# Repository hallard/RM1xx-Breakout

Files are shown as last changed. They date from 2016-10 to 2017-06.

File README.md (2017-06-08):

Laird LoRa/Bluetooth Low Energy Module breakout for RM1xx modules
=================================================================

These breakout are used to hold Lairdtech Lora/BLE [module][1] RM186 (868MHz) or RM191 (915MHz). There are 2 versions, one minimal to place on veroboard kind and one other the be placed on breadboard
They contains the following features

- Full version
  - I2C Pullups placement
  - CR2540 or LIR2450 battery holder
  - Resistor divider to measure battery voltage using analog pin
  - On board 3V3 regulator (so Lipo can be used) 
  - JST2 Lipo connector
  - FTDI connector
  - Prog/Debug connector footprint
  - Breadboard friendly

- Minimal version
  - I2C Pullups placement
  - Veroboard friendly

Version 1.1 fix the MCP1303 Regulator that was reversed

Boards have been ordered at PCBs.io and have been tested and they are working fine.

Detailed Description
====================

Look at the schematics for more informations.

- Full version 
  - Place R6 and R7 divider only if you need to measure Vbat from Analog SIO04
  - Place R3 and R4 only if you whan to use I2C devices

- Minimal version 
  - Place R1 and R2 only if you whan to use I2C devices

### Schematic 

**Full version**
Click to enlarge 
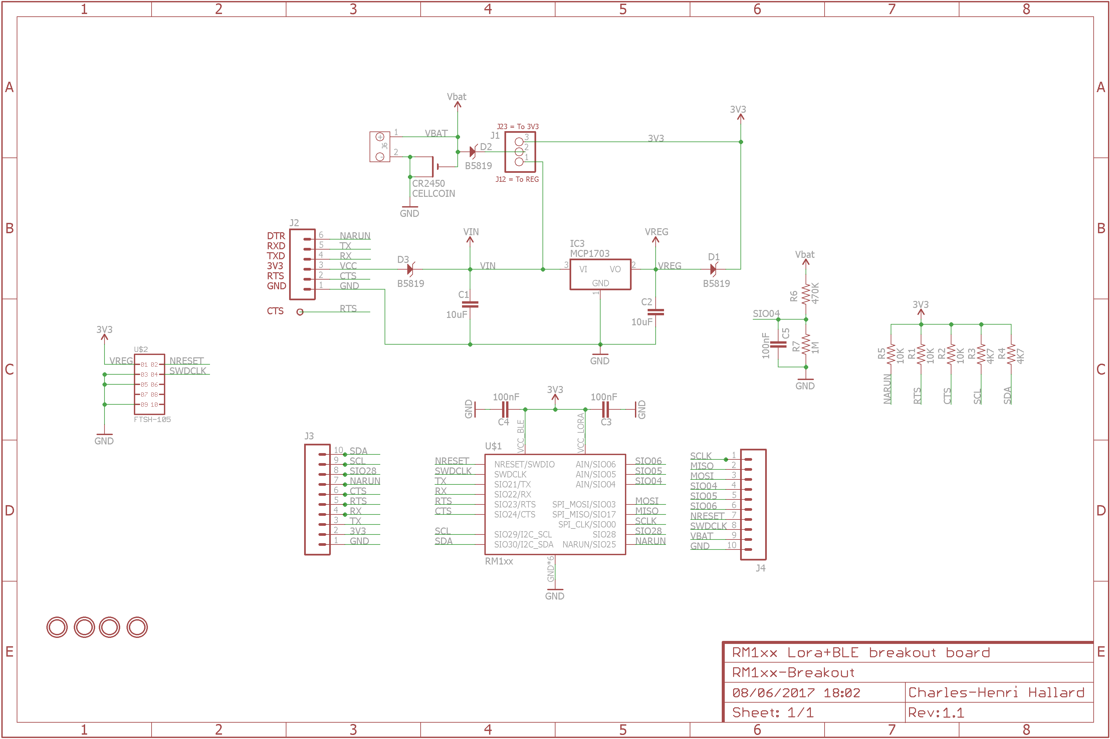
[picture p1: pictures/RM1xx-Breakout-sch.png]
  

**Minimal version**
Click to enlarge 
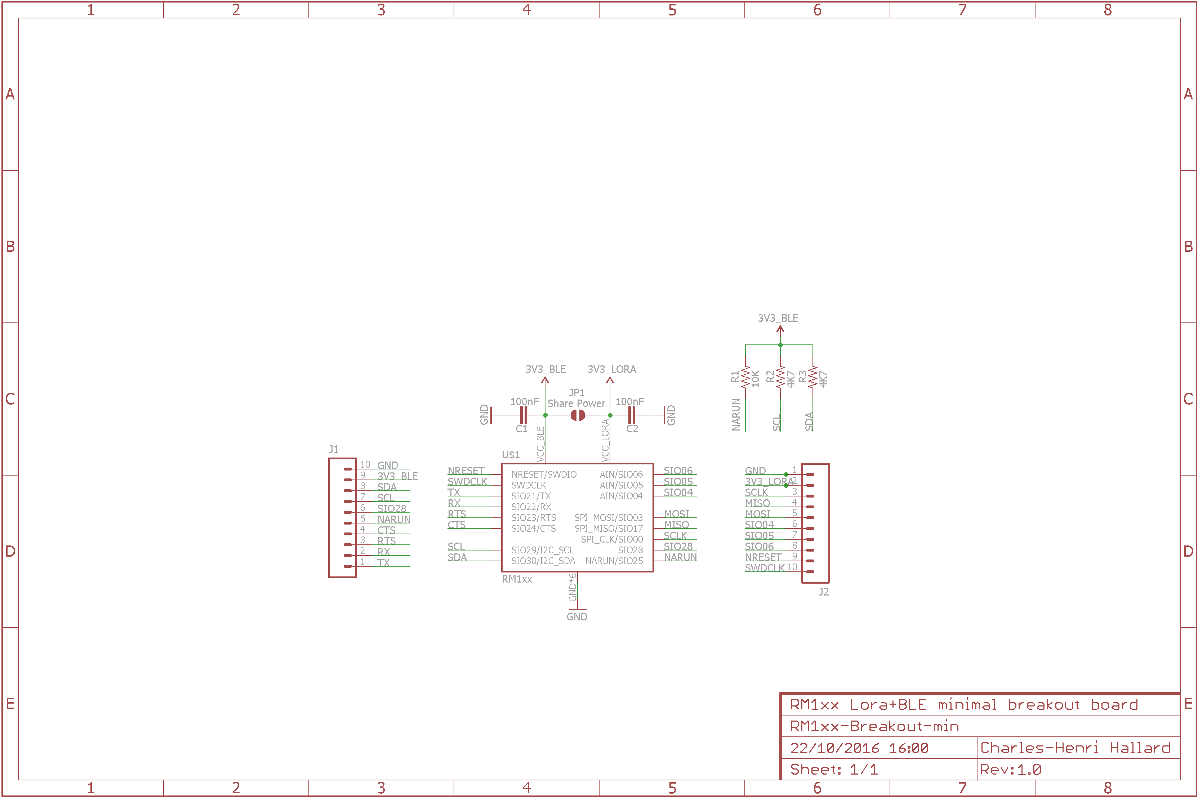
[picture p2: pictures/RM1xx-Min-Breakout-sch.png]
  

### Boards (Full Version)

**Top**    

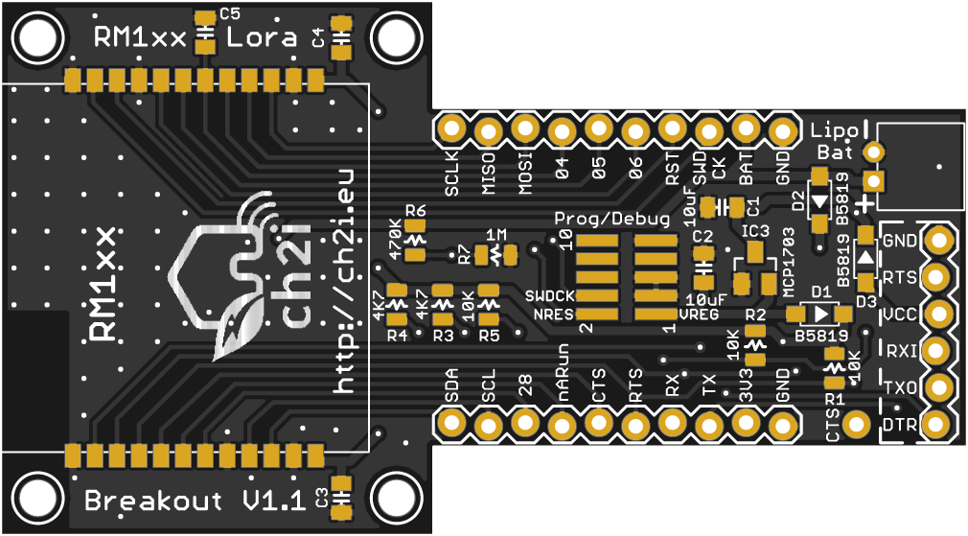
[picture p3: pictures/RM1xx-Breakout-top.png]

    
**Bottom**    

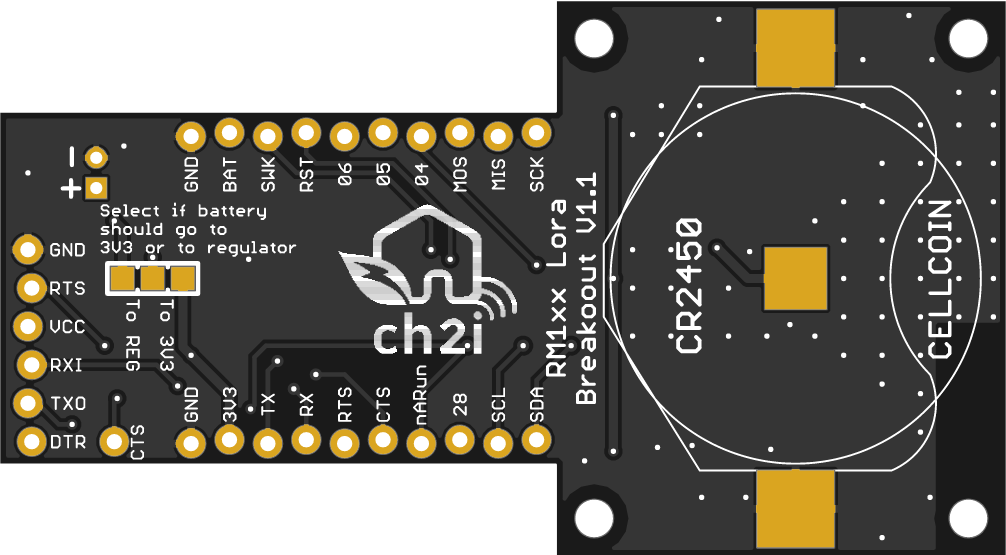
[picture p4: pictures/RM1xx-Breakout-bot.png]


You can order the PCB of this board at [PCBs.io][3] if you do so, PCBs.io give me little discount that allow me to buy some new created boards.

### Boards (Minimal Version)

**Top**    

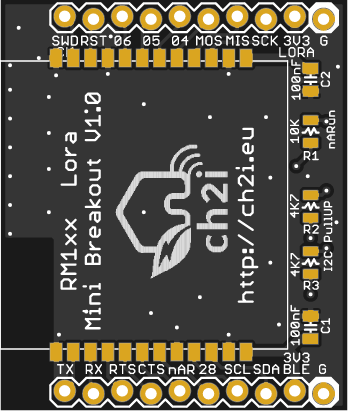
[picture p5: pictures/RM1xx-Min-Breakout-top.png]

    
**Bottom**    

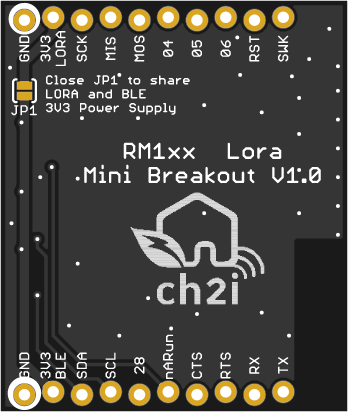
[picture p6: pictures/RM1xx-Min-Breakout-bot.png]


You can order the PCB of this minimal breakout board at [PCBs.io][4] if you do so, PCBs.io give me little discount that allow me to buy some new created boards.

### Assembled boards

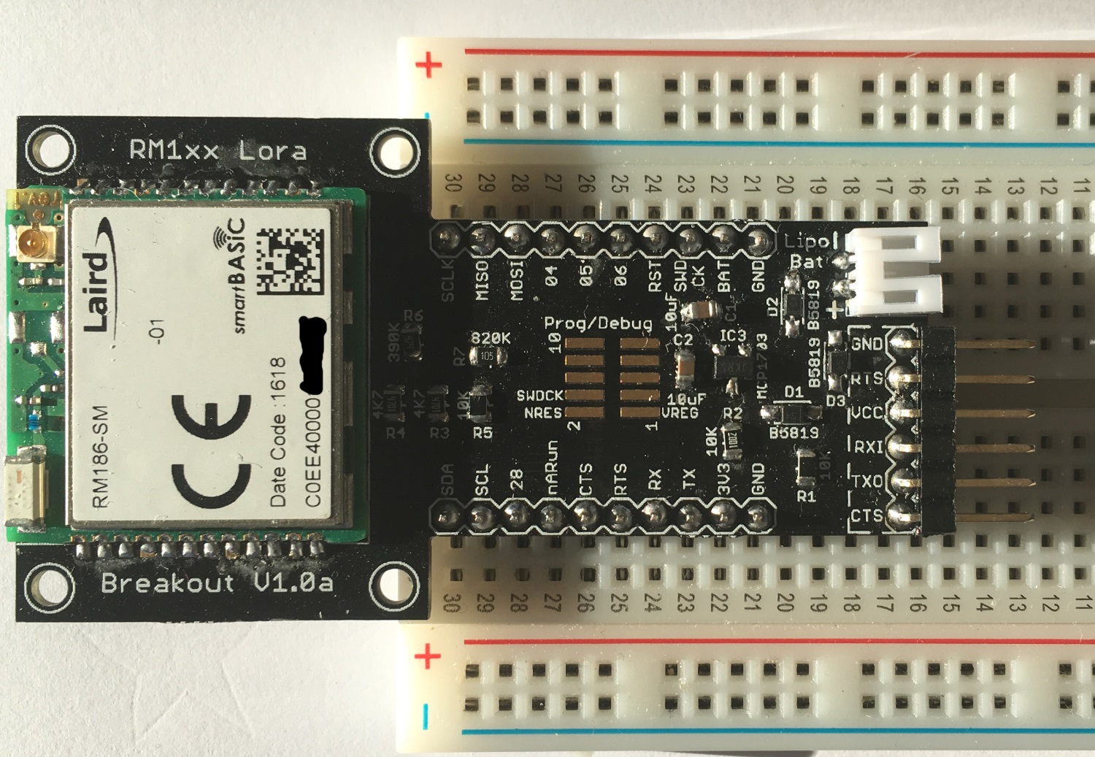
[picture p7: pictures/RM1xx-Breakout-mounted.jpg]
assembled


###License

You can do whatever you like with this design.

###Misc
See news and other projects on my [blog][2] 

[1]: http://www.lairdtech.com/products/rm1xx-lora-modules
[2]: https://hallard.me
[3]: https://PCBs.io/share/rY657 
[4]: https://PCBs.io/share/49GYW

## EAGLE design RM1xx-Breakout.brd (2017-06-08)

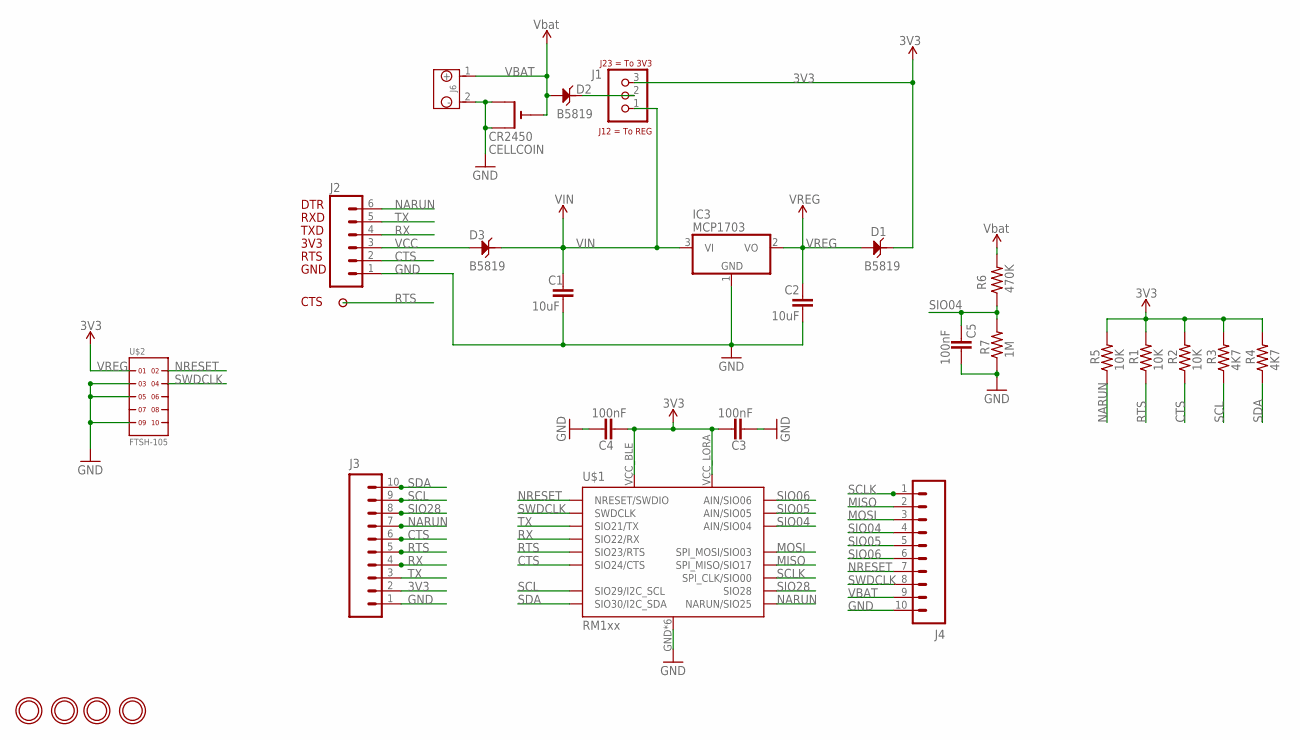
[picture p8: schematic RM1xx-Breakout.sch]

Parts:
C1, C2: 10uF; 0805-CAP
C3, C4, C5: 100nF; 0805-CAP
CELLCOIN: CR2450; CR2450-SMD
D1, D2, D3: B5819; SOD123-2.7X1.6
IC3: MCP1703; SOT23
J1: JUMPER_1X30805; JP3_0805
J2: M06SIP_LOCK; 1X06-SIP_LOCK
J3, J4: M10LOCK; 1X10_LOCK
J6: Lipo Battery; 2P-2.0-90D
P1: PADNORMAL; PAD
R1, R2, R5: 10K; 0805-RES
R3, R4: 4K7; 0805-RES
R6: 470K; 0805-RES
R7: 1M; 0805-RES
U$1: RM1xx; RM1XX
U$2: FTSH-105; FTSH-105-01-XXX-DV-K
U$3, U$6, U$7, U$8: MOUNTINGHOLE2.5; MOUNTINGHOLE_2.5_PLATED

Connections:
3V3: C3.1, C4.2, D1.2, J1.3, J3.2, R1.2, R2.2, R3.2, R4.2, R5.2, U$1.VCC_BLE, U$1.VCC_LORA
CTS: J2.2, J3.6, R2.1, U$1.SIO24 (SIO24/CTS)
GND: C1.2, C2.2, C3.2, C4.1, C5.1, CELLCOIN.+$1 (+), CELLCOIN.+$2 (+1), IC3.1 (GND), J2.1, J3.1, J4.10, J6.2 (-), R7.1, U$1.GND, U$1.GND1 (GND), U$1.GND2 (GND), U$1.GND3 (GND), U$1.GND4 (GND), U$1.GND5 (GND), U$2.3, U$2.5, U$2.9
MISO: J4.2, U$1.SIO17 (SPI_MISO/SIO17)
MOSI: J4.3, U$1.SIO03 (SPI_MOSI/SIO03)
unnamed: D2.2, J1.2
NARUN: J2.6, J3.7, R5.1, U$1.SIO25 (NARUN/SIO25)
NRESET: J4.7, U$1.RESET (NRESET/SWDIO), U$2.2
RTS: J3.5, P1.1, R1.1, U$1.SIO23 (SIO23/RTS)
RX: J2.4, J3.4, U$1.SIO22 (SIO22/RX)
SCL: J3.9, R3.1, U$1.SIO29 (SIO29/I2C_SCL)
SCLK: J4.1, U$1.SIO00 (SPI_CLK/SIO00)
SDA: J3.10, R4.1, U$1.SIO30 (SIO30/I2C_SDA)
SIO04: C5.2, J4.4, R6.1, R7.2, U$1.SIO04 (AIN/SIO04)
SIO05: J4.5, U$1.SIO05 (AIN/SIO05)
SIO06: J4.6, U$1.SIO06 (AIN/SIO06)
SIO28: J3.8, U$1.SIO28
SWDCLK: J4.8, U$1.SWDCLK, U$2.4
TX: J2.5, J3.3, U$1.SIO21 (SIO21/TX)
VBAT: CELLCOIN.-, D2.1, J4.9, J6.1 (+), R6.2
VCC: D3.1, J2.3
VIN: C1.1, D3.2, IC3.3 (VI), J1.1
VREG: C2.1, D1.1, IC3.2 (VO), U$2.1

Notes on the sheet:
DTR
RXD
TXD
3V3
RTS
GND
CTS

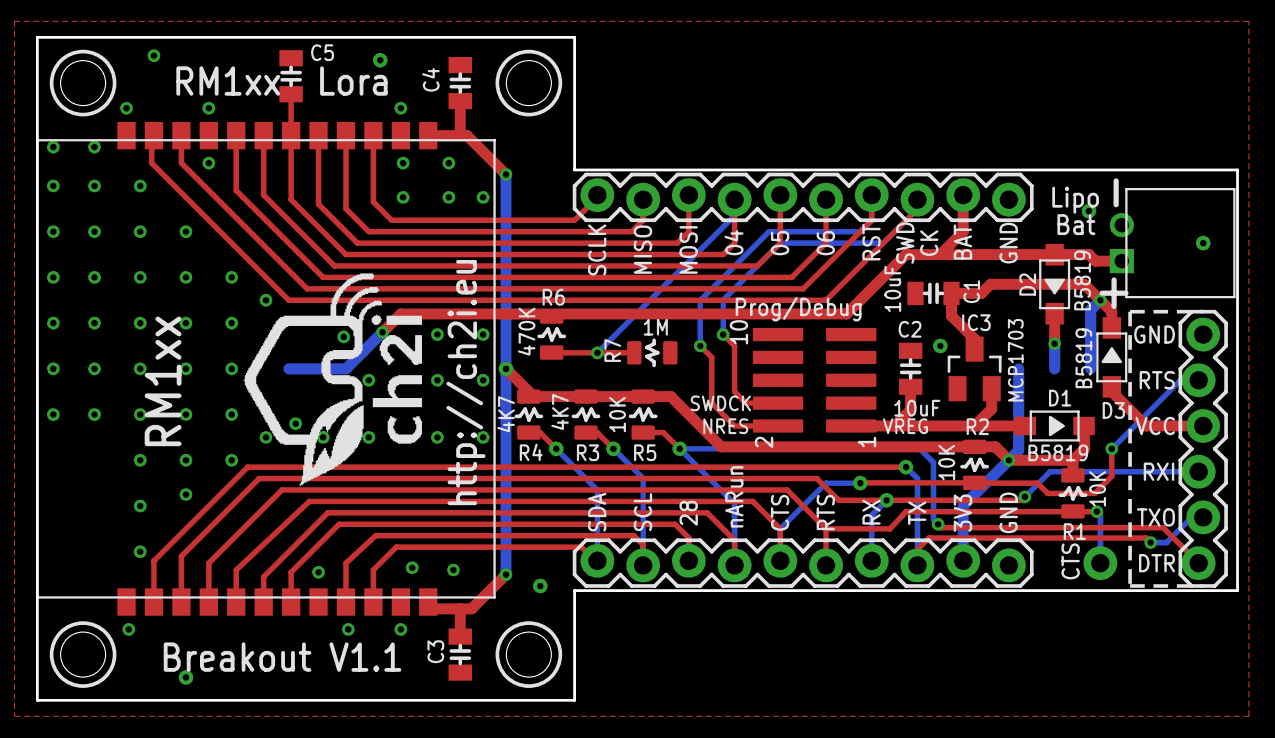
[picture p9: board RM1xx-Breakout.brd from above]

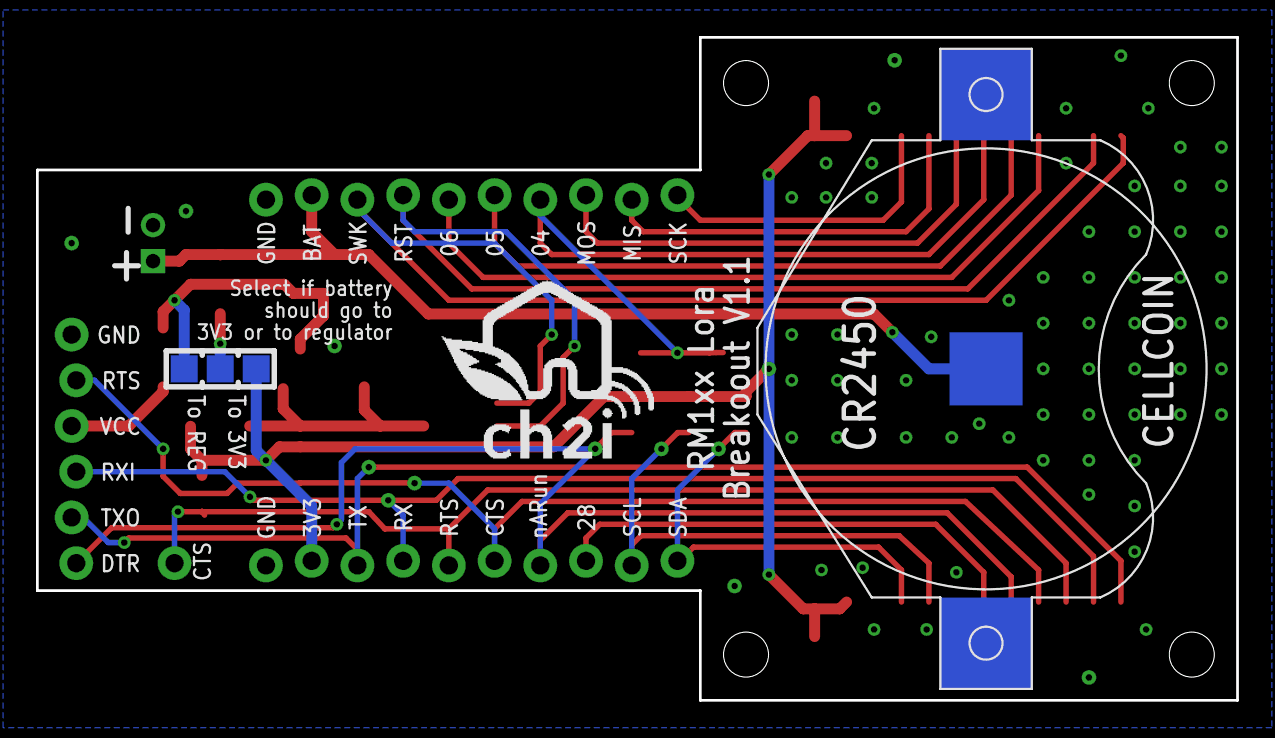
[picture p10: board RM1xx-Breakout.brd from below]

Board: 2 copper layers, 66.7 x 36.8 mm, 31 parts (3 on the bottom side), 23 nets.

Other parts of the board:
U$4, U$5: LOGO_CH2I_110MM

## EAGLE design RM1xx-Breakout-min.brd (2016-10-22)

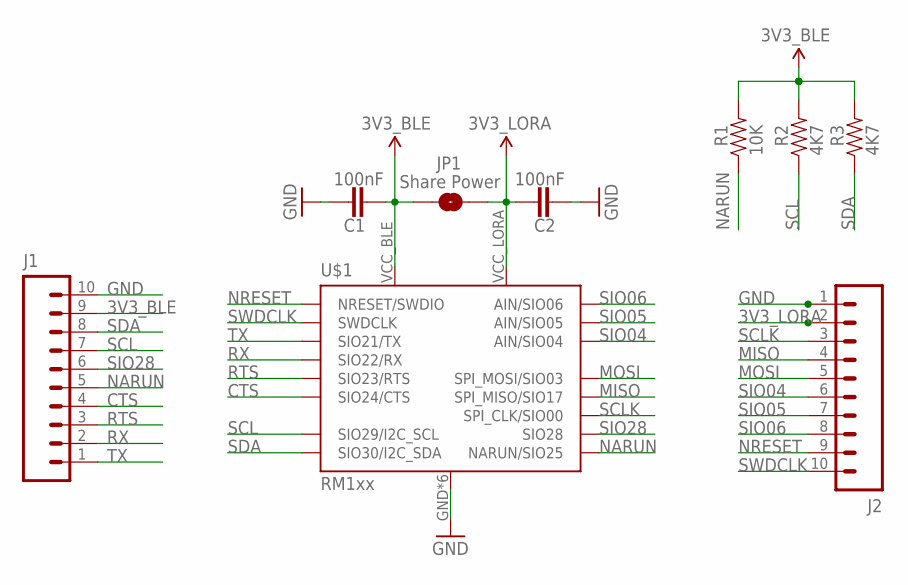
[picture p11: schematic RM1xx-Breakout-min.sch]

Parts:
C1, C2: 100nF; 0805-CAP
J1, J2: M10LOCK; 1X10_LOCK
JP1: Share Power; PAD-JUMPER-2-NO_YES_SILK
R1: 10K; 0805-RES
R2, R3: 4K7; 0805-RES
U$1: RM1xx; RM1XX

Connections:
3V3_BLE: C1.2, J1.9, JP1.1, R1.2, R2.2, R3.2, U$1.VCC_BLE
3V3_LORA: C2.1, J2.2, JP1.2, U$1.VCC_LORA
CTS: J1.4, U$1.SIO24 (SIO24/CTS)
GND: C1.1, C2.2, J1.10, J2.1, U$1.GND, U$1.GND1 (GND), U$1.GND2 (GND), U$1.GND3 (GND), U$1.GND4 (GND), U$1.GND5 (GND)
MISO: J2.4, U$1.SIO17 (SPI_MISO/SIO17)
MOSI: J2.5, U$1.SIO03 (SPI_MOSI/SIO03)
NARUN: J1.5, R1.1, U$1.SIO25 (NARUN/SIO25)
NRESET: J2.9, U$1.RESET (NRESET/SWDIO)
RTS: J1.3, U$1.SIO23 (SIO23/RTS)
RX: J1.2, U$1.SIO22 (SIO22/RX)
SCL: J1.7, R2.1, U$1.SIO29 (SIO29/I2C_SCL)
SCLK: J2.3, U$1.SIO00 (SPI_CLK/SIO00)
SDA: J1.8, R3.1, U$1.SIO30 (SIO30/I2C_SDA)
SIO04: J2.6, U$1.SIO04 (AIN/SIO04)
SIO05: J2.7, U$1.SIO05 (AIN/SIO05)
SIO06: J2.8, U$1.SIO06 (AIN/SIO06)
SIO28: J1.6, U$1.SIO28
SWDCLK: J2.10, U$1.SWDCLK
TX: J1.1, U$1.SIO21 (SIO21/TX)

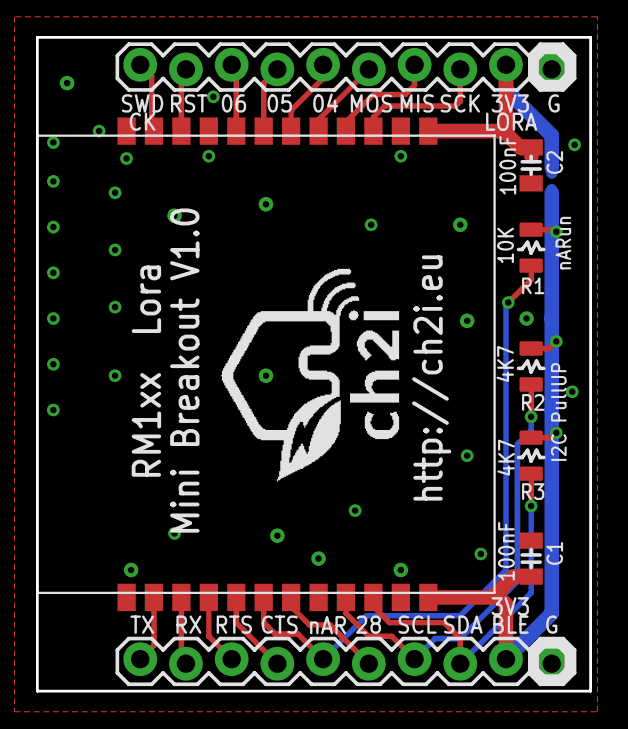
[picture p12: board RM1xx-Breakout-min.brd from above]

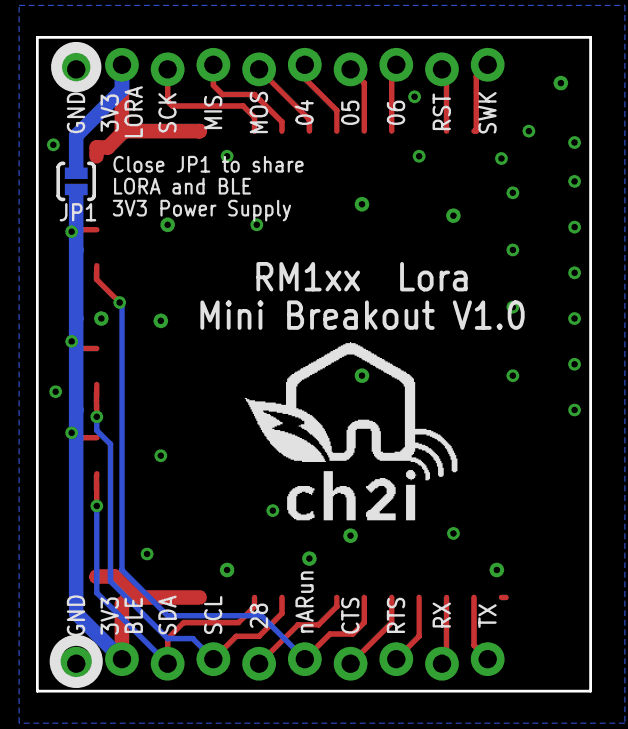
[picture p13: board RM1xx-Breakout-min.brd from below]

Board: 2 copper layers, 30.7 x 36.3 mm, 11 parts (2 on the bottom side), 19 nets.

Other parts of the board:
U$2, U$4: LOGO_CH2I_110MM

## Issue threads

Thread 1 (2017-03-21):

Vin and Vout switched around

Bonobo79, 2017-03-21:
I think the voltage regulator isn't connected properly. The input and output are switched around on the schematic?

looking4ward, 2017-06-08:
Yes, it is wrong. The Vin and Vout are switched in the design.
Besides that, the common voltage regulators have mirrored connections.
See images:
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

Assembled board showing the MCP1703:
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

Schema of MCP1703:
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

hallard, 2017-06-08:
Guys,
Absolutely you're right, amazing that nobody seen this before, it's not used by powering through FTDI ;-)
I'm making some modifications

hallard, 2017-06-08:
New version v1.1 is in this repo
PCBs.io link is https://PCBs.io/share/rY657

JoeKlimcak, 2022-05-29:
@hallard Any chance you can share the new version through a different platform please? PCBs.io is no longer operational and I could really use the above

hallard, 2022-05-30:
@JoeKlimcak you can submit directly the .brd file from this repo to oshpark, that's it :-)
https://oshpark.com/

JoeKlimcak, 2022-05-31:
Thank you!

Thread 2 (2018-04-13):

[Help] BLE firmware update

ricardosousa55, 2018-04-13:
Hi,

I recently got my self a RM186 module(without the Laird DVK) and I'm trying to change the BLE firmware from central do peripherical so I can make this connectable to other devices...

So the problem is that I got here a Segger J-Link Base, which I bought on purpose to program this chip and I'm not being able to detect the RM186 with the Segger. It seems to be all good with Segger, but I'm not sure with RM186.

I'm using the same connections they use on their dev board and already tried other possible ways.(VCC,GND,SWDIO,SWDCLK)

I was hoping you could help me with this, since you used the module without Laird DVK.

Best Regards, Ricardo Sousa.

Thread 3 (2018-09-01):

Library missing

sslupsky, 2018-09-01:
I tried to open the design files with KiCad but am missing the library.  Could you please upload the schematic symbol and pcb footprint libraries?

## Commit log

2016-07-17 Changed PCBs.io link
2016-07-17 removed copper on mounting holes
    [RM1xx-Breakout.brd, RM1xx-Breakout.sch]
2016-07-17 version 1.0b
    Removed copper from mounting holes
    Added ground via under RM1xx module
    [RM1xx-Breakout.brd, RM1xx-Breakout.sch]
2016-10-22 Added Minimal Breakout
    [RM1xx-Breakout-min.brd, RM1xx-Breakout-min.sch]
2017-06-08 Version 1.1
    [RM1xx-Breakout.brd, RM1xx-Breakout.sch]

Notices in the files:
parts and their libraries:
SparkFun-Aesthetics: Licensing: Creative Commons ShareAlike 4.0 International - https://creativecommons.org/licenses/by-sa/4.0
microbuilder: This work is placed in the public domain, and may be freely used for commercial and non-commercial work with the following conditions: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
